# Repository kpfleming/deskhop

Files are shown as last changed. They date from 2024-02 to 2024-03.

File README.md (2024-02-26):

#  DeskHop - Fast Desktop Switching
## JLCPCB version (see below)

Did you ever notice how, in the crazy world of tech, there's always that one quirky little project trying to solve a problem so niche that its only competitors might be a left-handed screwdriver and a self-hiding alarm clock?

I use two different computers in my daily workflow and share a single keyboard/mouse pair between them. Trying several USB switching boxes found on Amazon made me realize they all suffer from similar issues - it takes a while to switch, the process is quite clumsy when trying to find the button and frankly, it just doesn't get any better with time. 

All I wanted was a way to use a keyboard shortcut to quickly switch outputs, paired with the ability to do the same by magically moving the mouse pointer between monitors. This project enables you to do both, even if your computers run different operating systems!



## Features

- Completely **free and open source**
- No noticeable delay when switching
- Simply drag the mouse pointer between computers
- No software installed
- Affordable and obtainable components (<15€)
- 3D printable snap-fit case
- Full Galvanic isolation between your outputs
- Works with Linux, macOS and Windows

------

## How it works

The device acts as an intermediary between your keyboard/mouse and the computer, establishing and maintaining connections with both computers at once. Then it chooses where to forward your mouse and keystrokes to, depending on your selection. Keyboard follows the mouse and vice versa, so just dragging the mouse to the other desktop will switch both.

## Mouse 

To get the mouse cursor to magically jump across, the mouse hid report descriptor was changed to use absolute coordinates and then the mouse reports (that still come in relative movements) accumulate internally, keeping the accurate tally on the position. 

When you try to leave the monitor area in the direction of the other monitor, it keeps the Y coordinate and swaps the maximum X for a minimum X, then flips the outputs. This ensures that the cursor seamlessly appears at the same height on the other monitor, enhancing the perception of a smooth transition.



 <p align="center"> Dragging the mouse from Mac to Linux automatically switches outputs. 
 </p>

-----
 
The actual switch happens at the very moment when one arrow stops moving and the other one starts.

## Keyboard

Acting as a USB Host and querying your keyboard periodically, it looks for a preconfigured hotkey in the hid report (usually Caps Lock for me). When found, it will forward all subsequent characters to the other output.

To have a visual indication which output you are using at any given moment, you can repurpose keyboard LEDs and have them provide the necessary feedback. 

It also remembers the LED state for each computer, so you can pick up exactly how you left it. 



## How to build

```
PICO_BOARD=pico PICO_SDK_PATH=/your/sdk/path cmake -S . -B build
cmake --build build
```

## Using pre-built images

Alternatively, you can use the [pre-built images](binaries/). Take the Pico board that goes to slot A on the PCB and hold the on-board button while connecting the cable.

It should appear as a USB drive on your system. Copy the corresponding board_A.uf2 file there and repeat the same with B.

## Upgrading firmware

Option 1 - Open the case, hold the button while connecting each Pico and copy the right uf2 to it.

Option 2 - Switch a board to BOOTSEL mode by using a special key combination (listed below). 

This will make the corresponding Pico board enter the bootloader upgrade mode and act as USB flash drive. Now you can drag-and-drop the .uf2 file to it (you might need to plug in your mouse directly).

## Misc features

### Mouse slowdown

Ever tried to move that YT video slider to a specific position but your mouse moves too jumpy and suddenly you are moving your hand super-carefully like you're 5 and playing "Operation" all over again?

**Press right CTRL + right ALT** to toggle a slow-mouse mode. The mouse pointer will slow down considerably, enabling you to get the finer precision work done and still have your mouse moving normally by quickly pressing the same keys again.

### Switch Lock

If you want to lock yourself to one screen, use ```RIGHT CTRL + L```.
This will make sure you won't accidentally leave your current screen. To turn off, press the same key combo again.

### Screensaver

Supposedly built in to prevent computer from entering standby, but truth be told - it is just fun to watch. Off by default, will make your mouse pointer bounce around the screen like a Pong ball. When enabled, it activates after a period of inactivity defined in user config header and automatically switches off as soon as you send any output towards that screen. 



## Hardware

[The circuit](schematics/DeskHop.pdf) is based on two Raspberry Pi Pico boards, chosen because they are cheap (4.10 € / pc), can be hand soldered and most suppliers have them in stock.

The Picos are connected using UART and separated by an Analog Devices ADuM1201 dual-channel digital isolator (~3€). 

While they normally don't have support for dual USB, thanks to an [amazing project](https://github.com/sekigon-gonnoc/Pico-PIO-USB) where USB is implemented using the programmable IO wizardry found in RP2040, there is support for it to act both as an USB host and device.  

## PCB

To keep things as simple as possible for DIY builds, the traces were kept on one side and the number of parts kept to a theoretical minimum.



USB D+/D- differential lines should be identical in length, but they are slightly asymmetrical on purpose to counter the length difference on the corresponding GPIO traces PICO PCB itself, so the overall lengths should match.

Zd (differential impedance) is aimed as 90 ohm (managed to get ~107, close enough :)).

The thickness is designed to be 1.6 mm for snap-fit to work as expected.

Planned changes:
- Add 15 ohm resistors for D+ / D- lines
- Add decoupling capacitance near VBUS line on USB-A connector (~100 uF)
- Add an ESD protection device near the USB connector
- Add indications on the silkscreen for pin1 on the ADuM1201
- Add indications on the silkscreen for which Raspberry Pi Pico pins need to be soldered

... done, waiting on PCBs to re-test and verify everything. Stay tuned for an updated version!

## Case

Since I'm not very good with 3d, the case is [simple and basic](case/) but does the job. It should be easy to print, uses ~33g of filament and takes a couple of hours.

Horizontal PCB movements are countered by pegs sliding through holes and vertical movements by snap-fit lugs on the side - no screws required.

Micro USB connectors on both boards are offset from the side of the case, so slightly larger holes should allow for cables to reach in. 

The lid is of a snap-fit design, with a screwdriver slot for opening. The markings on top are recessed and can be finished with e.g. crayons to give better contrast (or simply left as-is).



## Bill of materials

Note that this fork of the project has been converted to use parts
from [LCSC](https://www.lcsc.com/), specifically parts that are kept
in stock at JLCPCB. This reduces costs and shortens assembly times,
but is only useful if you plan on ordering fully-assembled boards from
JLCPCB.

Prices quoted below are from a qty 10 unit order on 2024-02-26.

| Component | Qty | LCSC SKU | Unit Price / $ | Price / $|
|---|-----|---|---|---|
| Raspberry Pi Pico  | 2 | C7203002 | 5.93 | 11.85 |
| ISO7721DRRZ | 1 | C366164  | 0.56 |  0.56 |
| Cap 1206 SMD 100nF | 2 | C2858367 | 0.013 |  0.03 |
| USB-A PCB conn. | 2 | C42411 | 0.049 |  0.10 |
| Headers 2.54 1x03  | 2 | C2915006 | 0.176 |  0.35 |
| | | | | |
| | | | Total | 12.89 |

Additional steps:

 - making the PCB ([Gerber provided](pcb/), choose 1.6 mm thickness)
 - 3d printing the case ([stl files provided](case/), ~33g filament)

## Assembly guide

If you have some experience with electronics, you don't need this. However, some of you might not, and in that case this video might help guide you through the process. Please note, after soldering you should clean the flux from the PCB to prevent corrosion. 

The standard process to do that is using isopropyl alcohol and an old toothbrush. But guess what? I'm not putting my old toothbrush online, so you'll just have to improvise that part :)

PCB Assembly Guide (https://www.youtube.com/watch?v=LxI9NYi_oOU)

## Usage guide

### Keyboard shortcuts

_Firmware upgrade_
- ```Right Shift + F12 + Left Shift + A``` - put board A in FW upgrade mode
- ```Right Shift + F12 + Left Shift + B``` - put board B in FW upgrade mode

_Usage_
- ```Right CTRL + Right ALT``` - Toggle slower mouse mode
- ```Right CTRL + L``` - Lock/Unlock mouse desktop switching
- ```Caps Lock``` - Switch between outputs

_Config_
- ```Right Shift + F12 + D``` - remove flash config
- ```Right Shift + F12 + Y``` - save screen switch offset
- ```Right Shift + F12 + S``` - turn on/off screensaver option

### Switch cursor height calibration

This step is not required, but it can be handy if your screens are not perfectly aligned or differ in size. The objective is to have the mouse pointer come out at exactly the same height.



Just park your mouse on the LARGER screen at the height of the smaller/lower screen (illustrated) and press ```Right Shift + F12 + Y```. Your LED (and caps lock) should flash in confirmation.

Repeat for the bottom border (if it's above the larger screen's border). This will get saved to flash and it should keep this calibration value from now on.

### Other configuration

Mouse speed can now be configured per output screen and per axis. If you have multiple displays under Linux, your X speed is probably too fast, so you need to configure it in user_config.h and rebuild. In the future, this will be configurable without having to do that.

### Functional verification

When you connect a new USB peripheral, the board will flash the led twice, and instruct the other board to do the same. This way you can test if USB and outgoing communication works for each board.

Do this test by first plugging the keyboard on one side and then on the other. If everything is OK, leds will flash quickly back and forth in both cases.

## Security and Safety

Some features are missing on purpose, despite the fact it would make the device easier to use or simpler to configure. Here is a quick breakdown of these decisions:

- There is no copy-paste or *any* information sharing between systems. This prevents information leakage.
- No webhid device management or any inbound connectivity from the output computers, with the only exception of standard keyboard LED on/off messages, hard limited to 1 byte of data.
- No FW upgrade triggering from the outputs. Only explicit and deliberate user action through a special keyboard shortcut may do that.
- No plugged-in keyboard/mouse custom endpoints are exposed or information forwarded towards these devices. Their potential vulnerabilities are effectively firewalled from the computer.
- No input history is allowed to be retained.
- Outputs are physically separated and galvanically isolated with a minimal isolation voltage of 2kV.
- All packets exchanged between devices are of fixed length, no code is transferred and no raw config exchange of any kind can take place.
- There is no bluetooth or wifi, networking, Internet access, usb drives etc.
- No connected computer is considered trusted under any circumstances.
- Entirety of the code is open source, without any binary blobs and thoroughly commented to explain its purpose. I encourage you to never trust anyone and always make sure you know what you are running by doing a manual audit.

This still doesn't guarantee anything, but I believe it makes a reasonable set of ground rules to keep you safe and protected.

## FAQ

1. I just have two Picos, can I do without a PCB and isolator?

*Sure. Having an isolator is recommended but it should work without it.*

2. What happens if I have two different resolutions on my monitors?

*The mouse movement is done in abstract coordinate space and your computer figures out how that corresponds with the physical screen, so it should just work.*

3. Where can I buy it?

*I'm not selling anything, this is just a personal, non-commercial hobby project.*

*[update] There is a manufacturing/assembly company in China that might offer PCBs in qty of 1, assembled boards and boards + case, so stay tuned.*

*I **don't want to take any commission** on this - the only goal is to provide an alternative for people who don't feel confident enough to assemble the boards themselves.*

4. When the active screen is changed via the mouse, does the keyboard follow (and vice versa)?

*Yes, the idea was to make it behave like it was one single computer.*

5. Will this work with keyboard/mouse combo dongles, like the Logitech Unifying receiver?

*Not tested yet, but the latest version might actually work (please provide feedback).*

6. Will this work with wireless mice and keyboards that have separate wireless receivers (one for the mouse, another for the keyboard)?

*It should work - tried an Anker wireless mouse with a separate receiver and that worked just fine.*

7. I have issues with build or compilation

*Check out the [Troubleshooting Wiki](https://github.com/hrvach/deskhop/wiki/Troubleshooting) that might have some answers.*

## Software Alternatives

There are several software alternatives you can use if that works in your particular situation.

1. [Barrier](https://github.com/debauchee/barrier) - Free, Open Source
2. [Input Leap](https://github.com/input-leap/input-leap) - Free, Open Source
3. [Synergy](https://symless.com/synergy) - Commercial
4. [Mouse Without Borders](https://www.microsoft.com/en-us/garage/wall-of-fame/mouse-without-borders/) - Free, Windows only
5. [Universal Control](https://support.apple.com/en-my/HT212757) - Free, Apple thing

## Shortcomings

- Windows 10 broke HID absolute coordinates behavior in KB5003637, so you can't use more than 1 screen on Windows (mouse will stay on the main screen).
- Code needs cleanup, some refactoring etc.
- Occasional bugs and weird behavior.
- Not tested with a wide variety of devices, I don't know how it will work with your hardware. There is a reasonable chance things might not work out-of-the-box. 
- Advanced keyboards (with knobs, extra buttons or sliders) will probably face issues where this additional hardware doesn't work.
- Super-modern mice with 300 buttons might see some buttons not work as expected.
- NOTE: Both computers need to be connected and provide power to the USB for this to work (as each board gets powered by the computer it plugs into). Many desktops and laptops will provide power even when shut down nowadays. If you need to run with one board fully disconnected, you should be able to use a USB hub to plug both keyboard and mouse to a single port.

## Progress

So, what's the deal with all the enthusiasm? I can't believe it - please allow me to thank you all! I've never expected this kind of interest in a simple personal project, so the initial features are pretty basic (just like my cooking skills) and mostly cover my own usecase. Stay tuned for firmware updates that should bring wider device compatibility, more features and less bugs. As this is a hobby project, I appreciate your understanding for being time-constrained and promise to do the best I can.

Planned features:
- ~~Proper TinyUSB host integration~~ (done)
- ~~HID report protocol parsing, not just boot protocol~~ (mostly done)
- ~~Support for unified dongle receivers~~
- ~~Support for USB hubs and single-sided operation~~
- Configurable screens (partially)
- ~~Permament configuration stored in flash~~
- Better support for keyboards with knobs and mice with mickeys
- Unified firmware for both Picos
- ... and more!

Working on a *lite* version which provides basic functionality with just a single Pico W board, lowering the cost even further and enabling you to try it out even with no added hardware or PCB.

Mouse polling should now work at 1000 Hz (the dips in the graph is my arm hurting from all the movement :-)):

Mouse polling rate

## Disclaimer

I kindly request that anyone attempting to build this project understands and acknowledges that I am not liable for any injuries, damages, or other consequences. Your safety is important, and I encourage you to approach this project carefully, taking necessary precautions and assuming personal responsibility for your well-being throughout the process. Please don't get electrocuted, burned, stressed or angry. Have fun and enjoy! 

Happy switchin'!

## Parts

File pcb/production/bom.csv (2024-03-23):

Designator | Footprint | Quantity | Value | LCSC Part #
C101, C102, C202, C205, C206, C207, C208, C209, C210, C211, C212, C302, C305, C306, C307, C308, C309, C310, C311, C312 | 0402 | 20 | 100n | C541405
C201, C203, C204, C301, C303, C304 | 0402 | 6 | 2u2 | C541409
C214, C215, C314, C315 | 0402 | 4 | 1u | C106253
D201, D301 | 0603 | 2 | Active | C5875737
D202, D302 | SOD-323_L1.7-W1.3-LS2.6-RD-1 | 2 | 1N5817WS SJ | C2828424
J202, J302 | USB-C-SMD_G-SWITCH_GT-USB-7010ASV | 2 | Computer | C2988369
J203, J303 | USB-C-SMD_G-SWITCH_GT-USB-7010ASV | 2 | Power | C2988369
J204, J304 | USB-C-SMD_G-SWITCH_GT-USB-7010ASV | 2 | Device | C2988369
KEY201, KEY301 | KEY-SMD_4P-L4.2-W3.2-P2.20-LS4.6 | 2 | BOOTSEL | C470427
Q201, Q301 | SOT-23-3_L2.9-W1.3-P0.95-LS2.4-BR-1 | 2 | USB Power Switch | C2940629
R201, R301 | 0402 | 2 | 1K | C144789
R202, R302 | 0402 | 2 | 470R | C227095
R203, R204, R205, R206, R303, R304, R305, R306 | 0402 | 8 | 27R | C138021
R207, R208, R210, R211, R307, R308, R310, R311 | 0402 | 8 | 5K1 | C144745
R209, R212, R213, R309, R312, R313 | 0402 | 6 | 22K | C144778
U101 | SOIC-8_3.9x4.9mm_P1.27mm | 1 | Digital Isolator | C366164
U201, U301 | SOIC-8_L5.3-W5.3-P1.27-LS8.0-BL | 2 | 16Mb NOR Flash | C82317
U202, U302 | SOT-23-3_L3.0-W1.7-P0.95-LS2.9-BR | 2 | 3V3 250ma LDO Regulator | C347376
U203, U303 | RP2040-QFN-56 | 2 | Microcontroller | C2040
X201, X301 | OSC-SMD_4P-L3.2-W2.5-BL-1 | 2 | 12MHz CMOS Oscillator | C387348

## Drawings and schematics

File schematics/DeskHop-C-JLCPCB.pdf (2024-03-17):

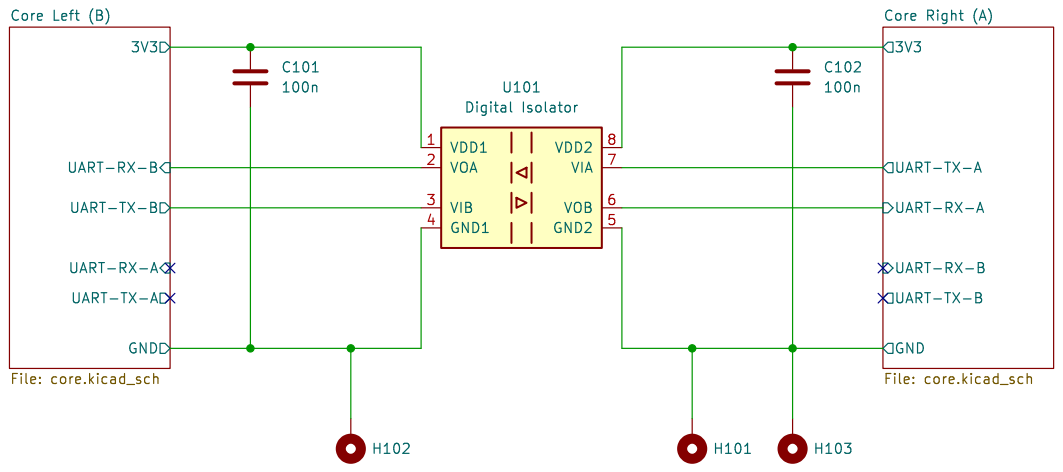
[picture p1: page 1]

UART-TX-B UART-RX-B UART-TX-A UART-RX-A Core Right (A) File: core.kicad_sch
3V3 GND

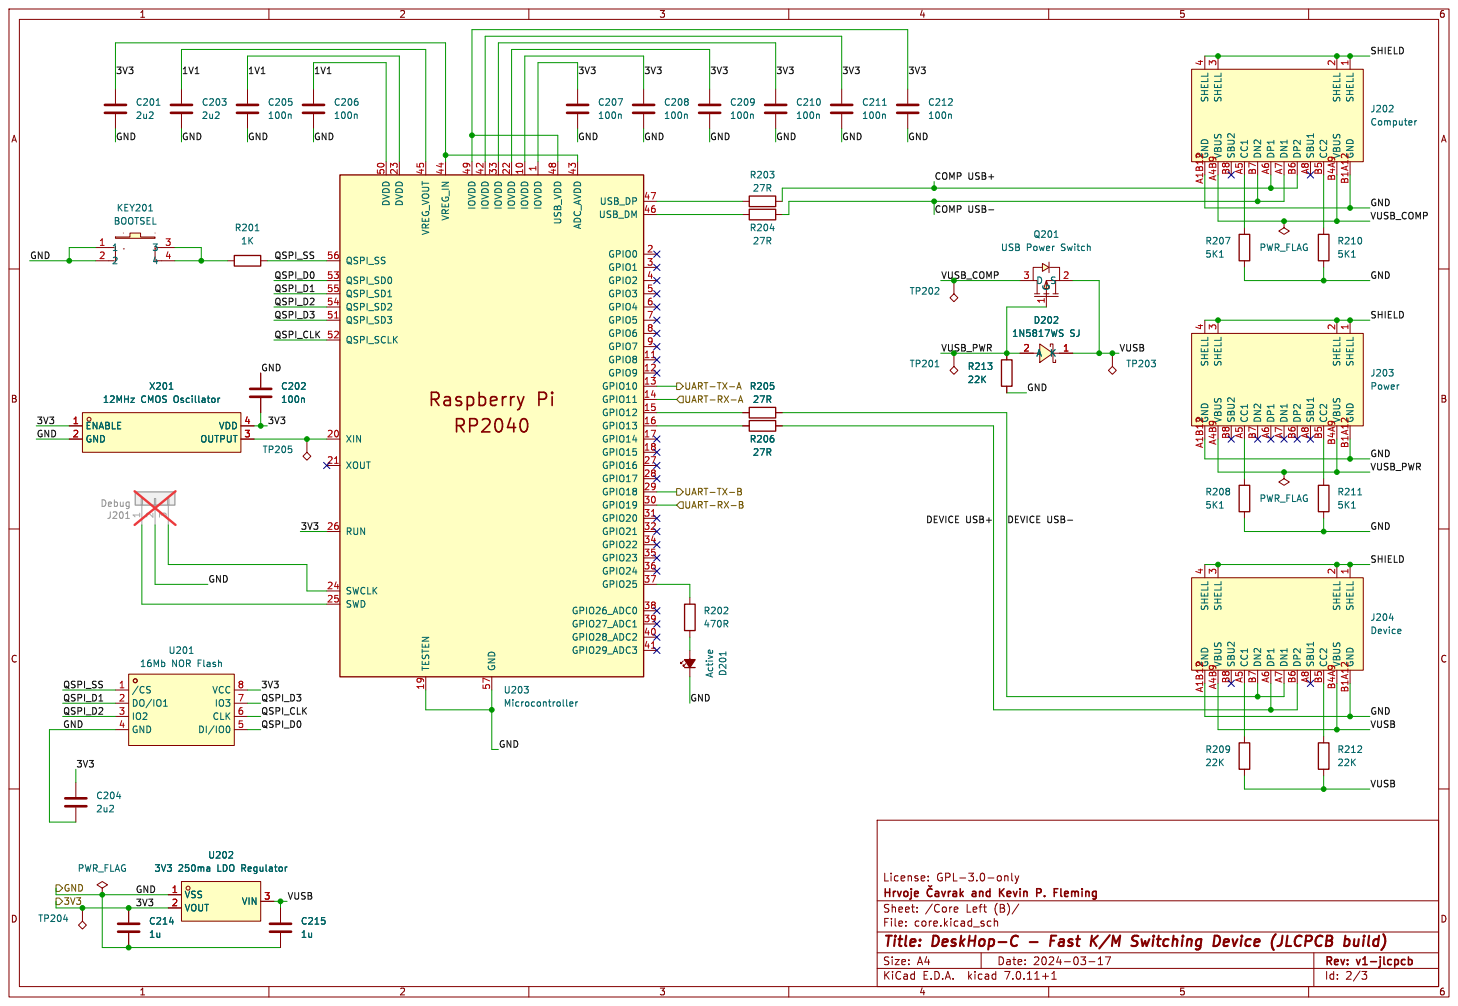
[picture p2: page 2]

COMP USB+ COMP USB- 3V3 GND

1 IOVDD 10 GPIO8 11 GPIO9 12 GPIO10 13 GPIO11 14 GPIO12 15 GPIO13 16 GPIO14 17 GPIO15 18 TESTEN 19 GPIO0 2 XIN 20 XOUT 21 IOVDD 22 DVDD 23 SWCLK 24 SWD 25 RUN 26 GPIO16 27 GPIO17 28 GPIO18 29 GPIO1 3 GPIO19 30 GPIO20 31 GPIO21 32 IOVDD 33 GPIO22 34 GPIO23 35 GPIO24 36 GPIO25 37 GPIO26_ADC0 38 GPIO27_ADC1 39 GPIO2 4 GPIO28_ADC2 40 GPIO29_ADC3 41 IOVDD 42 ADC_AVDD 43 VREG_IN 44 VREG_VOUT 45 USB_DM 46 USB_DP 47 USB_VDD 48 IOVDD 49 GPIO3 5 DVDD 50 QSPI_SD3 51 QSPI_SCLK 52 QSPI_SD0 53 QSPI_SD2 54 QSPI_SD1 55 QSPI_SS 56 GND 57 GPIO4 6 GPIO5 7 GPIO6 8 GPIO7 9 U203 Microcontroller SHELL

3 Debug ENABLE 1 GND 2 OUTPUT 3 VDD 4 X201

UART-RX-A UART-TX-A

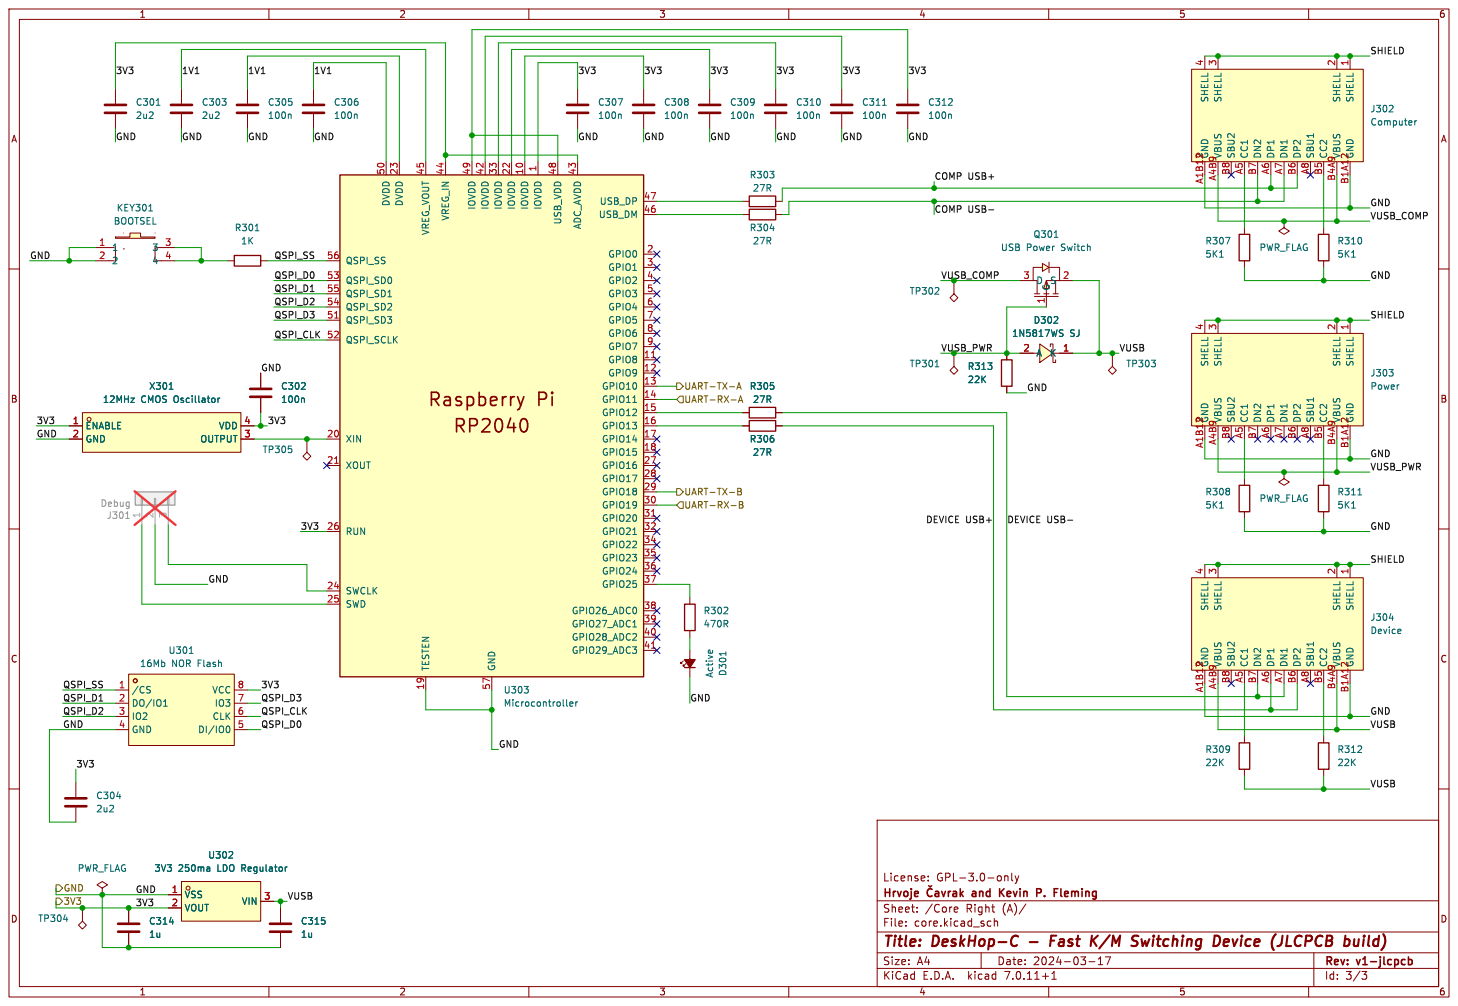
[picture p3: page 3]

COMP USB+ COMP USB- 3V3 GND

1 IOVDD 10 GPIO8 11 GPIO9 12 GPIO10 13 GPIO11 14 GPIO12 15 GPIO13 16 GPIO14 17 GPIO15 18 TESTEN 19 GPIO0 2 XIN 20 XOUT 21 IOVDD 22 DVDD 23 SWCLK 24 SWD 25 RUN 26 GPIO16 27 GPIO17 28 GPIO18 29 GPIO1 3 GPIO19 30 GPIO20 31 GPIO21 32 IOVDD 33 GPIO22 34 GPIO23 35 GPIO24 36 GPIO25 37 GPIO26_ADC0 38 GPIO27_ADC1 39 GPIO2 4 GPIO28_ADC2 40 GPIO29_ADC3 41 IOVDD 42 ADC_AVDD 43 VREG_IN 44 VREG_VOUT 45 USB_DM 46 USB_DP 47 USB_VDD 48 IOVDD 49 GPIO3 5 DVDD 50 QSPI_SD3 51 QSPI_SCLK 52 QSPI_SD0 53 QSPI_SD2 54 QSPI_SD1 55 QSPI_SS 56 GND 57 GPIO4 6 GPIO5 7 GPIO6 8 GPIO7 9 U303 Microcontroller SHELL

3 Debug ENABLE 1 GND 2 OUTPUT 3 VDD 4 X301

UART-RX-A UART-TX-A

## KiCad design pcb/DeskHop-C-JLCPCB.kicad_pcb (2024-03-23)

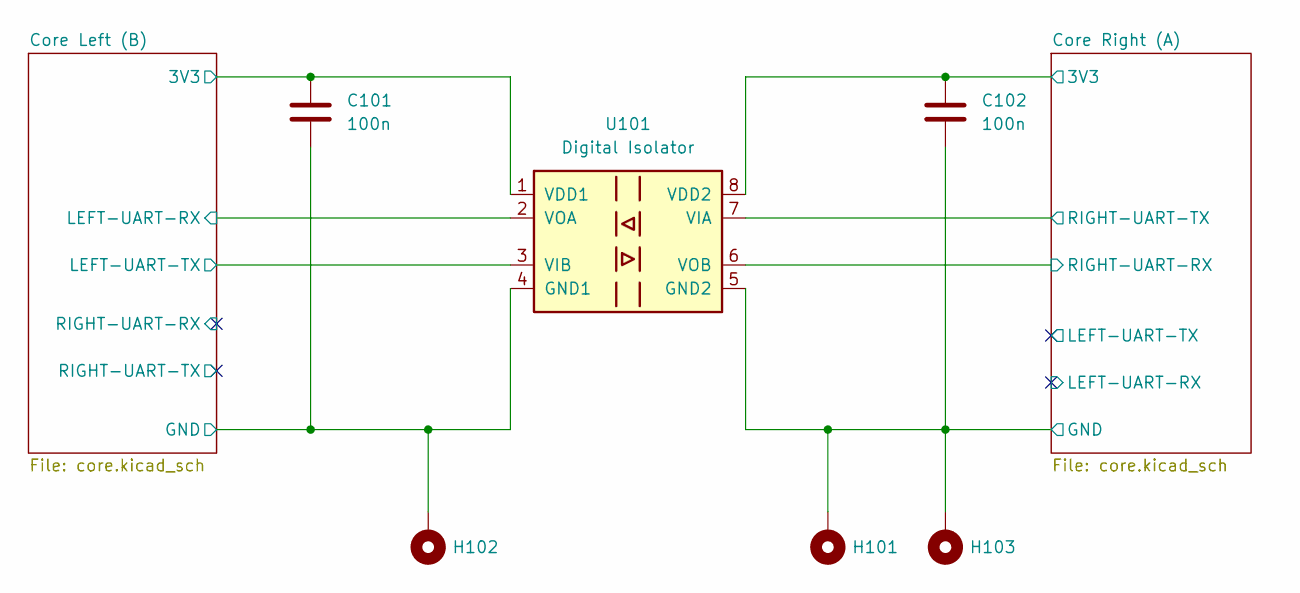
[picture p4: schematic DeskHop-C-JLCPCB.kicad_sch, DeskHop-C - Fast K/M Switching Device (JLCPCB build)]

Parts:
C101, C102: 100n; C_0402_1005Metric; MPN CC0402KRX5R5BB104; LCSC C541405
H101, H102, H103: MountingHole_Pad; MountingHole_2.7mm_M2.5_Pad_Via
U101: Digital Isolator; SOIC-8_3.9x4.9mm_P1.27mm; MPN ISO7721DR; LCSC C366164

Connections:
/Core Left (B)/3V3: C101.1, U101.1 (VDD1); also elsewhere on the board
/Core Left (B)/GND: C101.2, H102.1, U101.4 (GND1); also elsewhere on the board
/Core Left (B)/LEFT-UART-RX: U101.2 (VOA); also elsewhere on the board
/Core Left (B)/LEFT-UART-TX: U101.3 (VIB); also elsewhere on the board
/Core Right (A)/3V3: C102.1, U101.8 (VDD2); also elsewhere on the board
/Core Right (A)/GND: C102.2, H101.1, H103.1, U101.5 (GND2); also elsewhere on the board
/Core Right (A)/RIGHT-UART-RX: U101.6 (VOB); also elsewhere on the board
/Core Right (A)/RIGHT-UART-TX: U101.7 (VIA); also elsewhere on the board

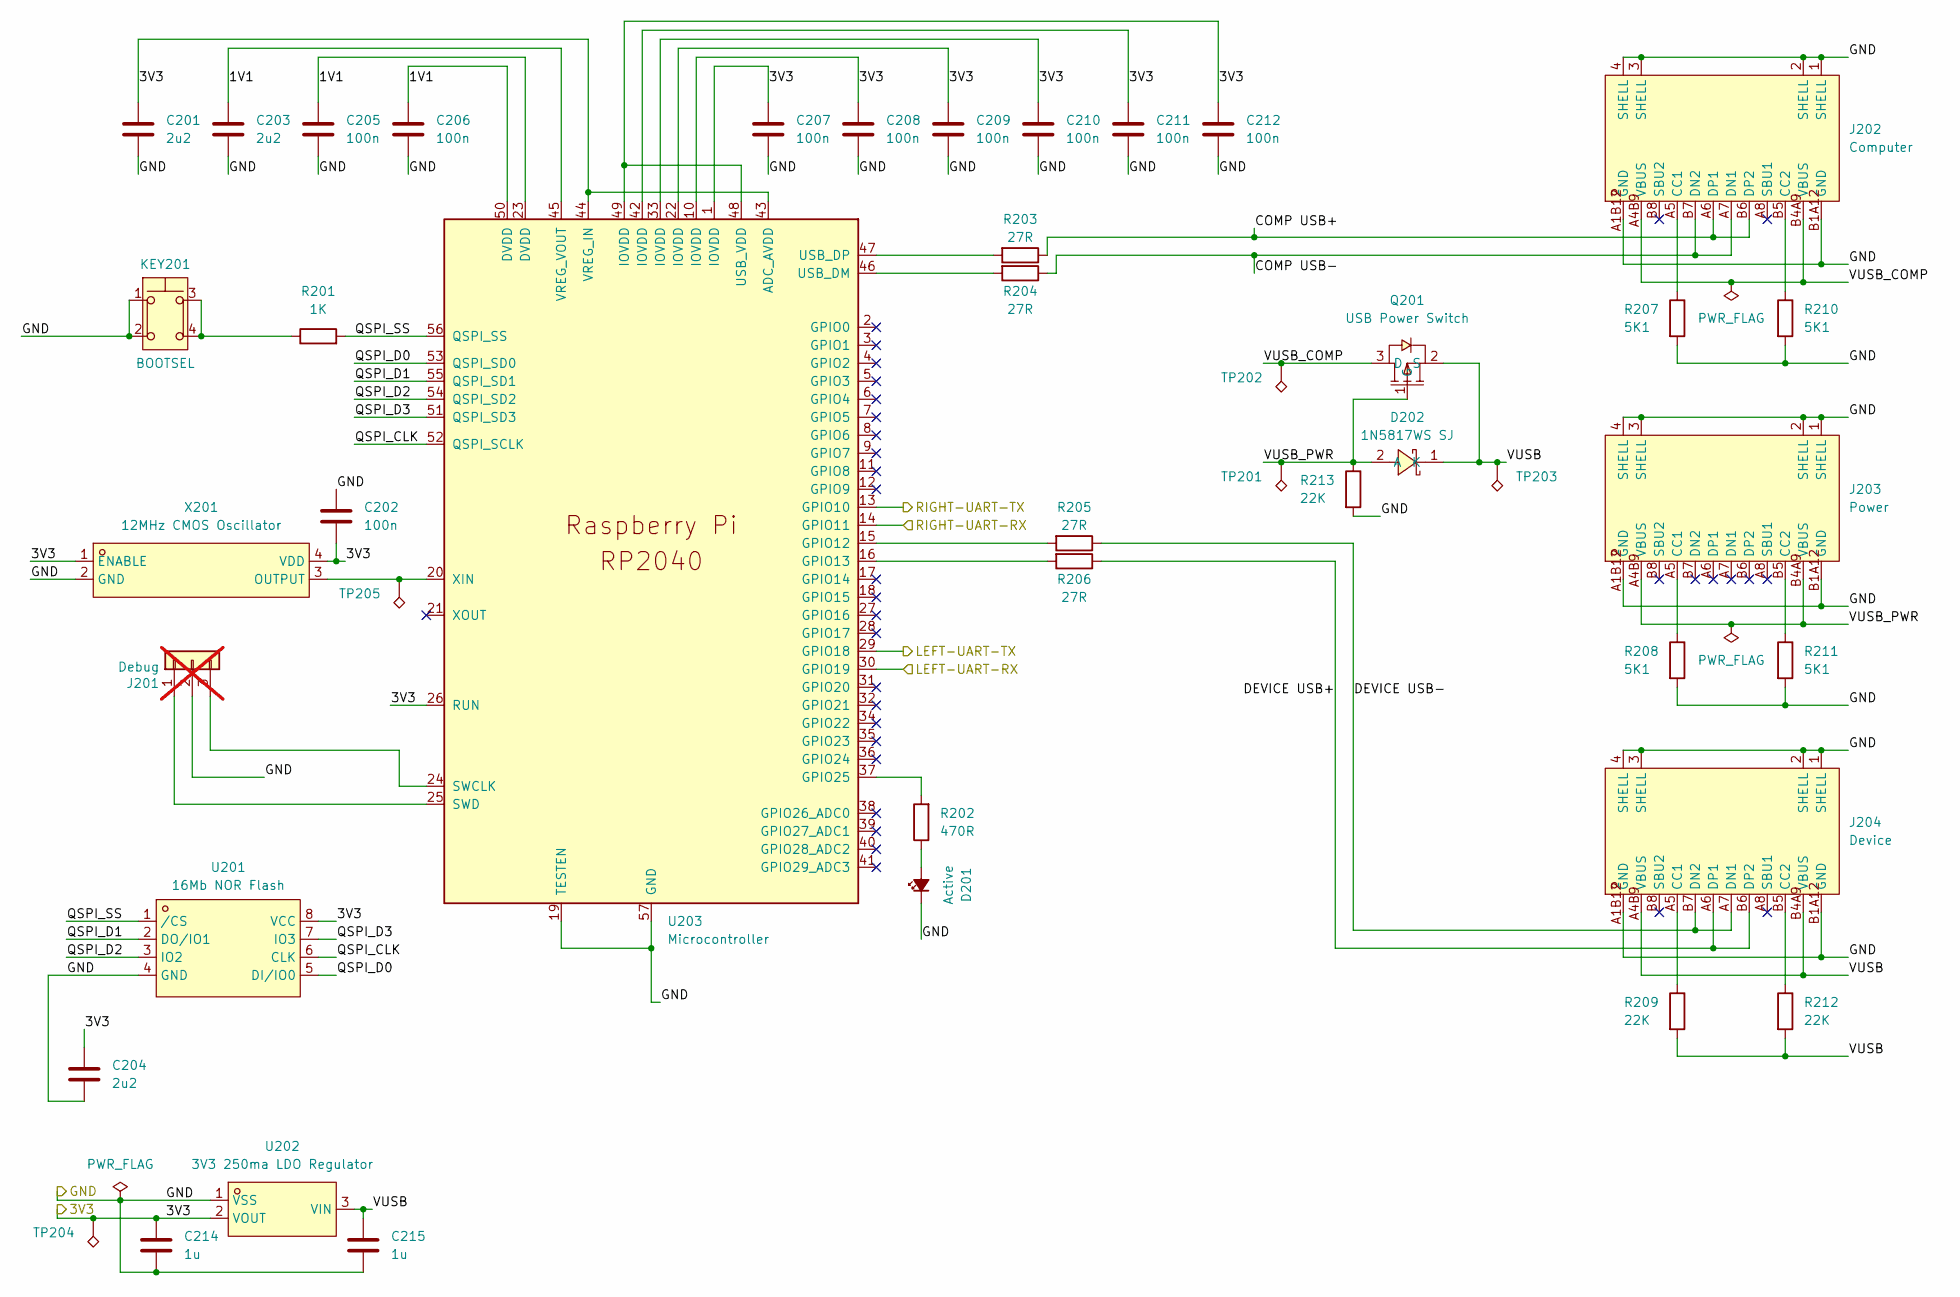
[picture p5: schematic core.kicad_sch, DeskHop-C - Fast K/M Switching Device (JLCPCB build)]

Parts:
C201, C203, C204: 2u2; C_0402_1005Metric; MPN CC0402KRX5R5BB225; LCSC C541409
C202, C205, C206, C207, C208, C209, C210, C211, C212: 100n; C_0402_1005Metric; MPN CC0402KRX5R5BB104; LCSC C541405
C214, C215: 1u; C_0402_1005Metric; MPN CC0402KRX5R5BB105; LCSC C106253
D201: Active; LED_0603_1608Metric; MPN NCD0805B2APG1608CGKC/T; LCSC C5875737
D202: 1N5817WS SJ; SOD-323_L1.7-W1.3-LS2.6-RD-1; MPN 1N5817WS; LCSC C2828424
J201: Debug; PinHeader_1x03_P2.54mm_Vertical; not fitted
J202: Computer; USB-C-SMD_G-SWITCH_GT-USB-7010ASV; MPN GT-USB-7010ASV; LCSC C2988369
J203: Power; USB-C-SMD_G-SWITCH_GT-USB-7010ASV; MPN GT-USB-7010ASV; LCSC C2988369
J204: Device; USB-C-SMD_G-SWITCH_GT-USB-7010ASV; MPN GT-USB-7010ASV; LCSC C2988369
KEY201: BOOTSEL; KEY-SMD_4P-L4.2-W3.2-P2.20-LS4.6; MPN SKRPASE010; LCSC C470427
Q201: USB Power Switch; SOT-23-3_L2.9-W1.3-P0.95-LS2.4-BR-1; MPN DMG2305UX; LCSC C2940629
R201: 1K; R_0402_1005Metric; MPN AC0402FR-071KL; LCSC C144789
R202: 470R; R_0402_1005Metric; MPN AC0402FR-07470RL; LCSC C227095
R203, R204, R205, R206: 27R; R_0402_1005Metric; MPN RC0402FR-0727RL; LCSC C138021
R207, R208, R210, R211: 5K1; R_0402_1005Metric; MPN AC0402FR-075K1L; LCSC C144745
R209, R212, R213: 22K; R_0402_1005Metric; MPN AC0402FR-0722KL; LCSC C144778
TP201, TP202, TP203, TP204, TP205: TestPoint_Alt; TestPoint_Pad_1.0x1.0mm
U201: 16Mb NOR Flash; SOIC-8_L5.3-W5.3-P1.27-LS8.0-BL; MPN W25Q16JVSSIQ; LCSC C82317
U202: 3V3 250ma LDO Regulator; SOT-23-3_L3.0-W1.7-P0.95-LS2.9-BR; MPN XC6206P332MR; LCSC C347376
U203: Microcontroller; RP2040-QFN-56; MPN RP2040; LCSC C2040
X201: 12MHz CMOS Oscillator; OSC-SMD_4P-L3.2-W2.5-BL-1; MPN S3D12.000000B20F30T; LCSC C387348

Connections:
/Core Left (B)/1V1: C203.2, C205.2, C206.2, U203.23 (DVDD), U203.45 (VREG_VOUT), U203.50 (DVDD)
/Core Left (B)/3V3: C201.2, C202.1, C204.1, C207.2, C208.2, C209.2, C210.2, C211.2, C212.2, C214.1, TP204.1, U201.8 (VCC), U202.2 (VOUT), U203.1 (IOVDD), U203.10 (IOVDD), U203.22 (IOVDD), U203.26 (RUN), U203.33 (IOVDD), U203.42 (IOVDD), U203.43 (ADC_AVDD), U203.44 (VREG_IN), U203.48 (USB_VDD), U203.49 (IOVDD), X201.1 (ENABLE), X201.4 (VDD); also elsewhere on the board
/Core Left (B)/COMP USB+: J202.A6 (DP1), J202.B6 (DP2), R203.1
/Core Left (B)/COMP USB-: J202.A7 (DN1), J202.B7 (DN2), R204.1
/Core Left (B)/DEVICE USB+: J204.A6 (DP1), J204.B6 (DP2), R205.1
/Core Left (B)/DEVICE USB-: J204.A7 (DN1), J204.B7 (DN2), R206.1
/Core Left (B)/GND: C201.1, C202.2, C203.1, C204.2, C205.1, C206.1, C207.1, C208.1, C209.1, C210.1, C211.1, C212.1, C214.2, C215.2, D201.1 (K), J201.2, J202.1 (SHELL), J202.2 (SHELL), J202.3 (SHELL), J202.4 (SHELL), J202.A1B12 (GND), J202.B1A12 (GND), J203.1 (SHELL), J203.2 (SHELL), J203.3 (SHELL), J203.4 (SHELL), J203.A1B12 (GND), J203.B1A12 (GND), J204.1 (SHELL), J204.2 (SHELL), J204.3 (SHELL), J204.4 (SHELL), J204.A1B12 (GND), J204.B1A12 (GND), KEY201.1, KEY201.2, R207.2, R208.2, R210.2, R211.2, R213.2, U201.4 (GND), U202.1 (VSS), U203.19 (TESTEN), U203.57 (GND), X201.2 (GND); also elsewhere on the board
/Core Left (B)/LEFT-UART-RX: U203.30 (GPIO19); also elsewhere on the board
/Core Left (B)/LEFT-UART-TX: U203.29 (GPIO18); also elsewhere on the board
/Core Left (B)/QSPI_CLK: U201.6 (CLK), U203.52 (QSPI_SCLK)
/Core Left (B)/QSPI_D0: U201.5 (DI/IO0), U203.53 (QSPI_SD0)
/Core Left (B)/QSPI_D1: U201.2 (DO/IO1), U203.55 (QSPI_SD1)
/Core Left (B)/QSPI_D2: U201.3 (IO2), U203.54 (QSPI_SD2)
/Core Left (B)/QSPI_D3: U201.7 (IO3), U203.51 (QSPI_SD3)
/Core Left (B)/QSPI_SS: R201.2, U201.1 (/CS), U203.56 (QSPI_SS)
/Core Left (B)/RIGHT-UART-RX: U203.14 (GPIO11)
/Core Left (B)/RIGHT-UART-TX: U203.13 (GPIO10)
/Core Left (B)/VUSB: C215.1, D202.1 (K), J204.A4B9 (VBUS), J204.B4A9 (VBUS), Q201.2 (S), R209.2, R212.2, TP203.1, U202.3 (VIN)
/Core Left (B)/VUSB_COMP: J202.A4B9 (VBUS), J202.B4A9 (VBUS), Q201.3 (D), TP202.1
/Core Left (B)/VUSB_PWR: D202.2 (A), J203.A4B9 (VBUS), J203.B4A9 (VBUS), Q201.1 (G), R213.1, TP201.1
unnamed: D201.2 (A), R202.1
unnamed: J201.1, U203.25 (SWD)
unnamed: J201.3, U203.24 (SWCLK)
unnamed: J202.A5 (CC1), R207.1
unnamed: J202.B5 (CC2), R210.1
unnamed: J203.A5 (CC1), R208.1
unnamed: J203.B5 (CC2), R211.1
unnamed: J204.A5 (CC1), R209.1
unnamed: J204.B5 (CC2), R212.1
unnamed: KEY201.3, KEY201.4, R201.1
unnamed: R206.2, U203.15 (GPIO12)
unnamed: R205.2, U203.16 (GPIO13)
unnamed: R202.2, U203.37 (GPIO25)
unnamed: R204.2, U203.46 (USB_DM)
unnamed: R203.2, U203.47 (USB_DP)
unnamed: TP205.1, U203.20 (XIN), X201.3 (OUTPUT)

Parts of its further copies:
C301, C303, C304: 2u2; C_0402_1005Metric; MPN CC0402KRX5R5BB225; LCSC C541409
C302, C305, C306, C307, C308, C309, C310, C311, C312: 100n; C_0402_1005Metric; MPN CC0402KRX5R5BB104; LCSC C541405
C314, C315: 1u; C_0402_1005Metric; MPN CC0402KRX5R5BB105; LCSC C106253
D301: Active; LED_0603_1608Metric; MPN NCD0805B2APG1608CGKC/T; LCSC C5875737
D302: 1N5817WS SJ; SOD-323_L1.7-W1.3-LS2.6-RD-1; MPN 1N5817WS; LCSC C2828424
J301: Debug; PinHeader_1x03_P2.54mm_Vertical; not fitted
J302: Computer; USB-C-SMD_G-SWITCH_GT-USB-7010ASV; MPN GT-USB-7010ASV; LCSC C2988369
J303: Power; USB-C-SMD_G-SWITCH_GT-USB-7010ASV; MPN GT-USB-7010ASV; LCSC C2988369
J304: Device; USB-C-SMD_G-SWITCH_GT-USB-7010ASV; MPN GT-USB-7010ASV; LCSC C2988369
KEY301: BOOTSEL; KEY-SMD_4P-L4.2-W3.2-P2.20-LS4.6; MPN SKRPASE010; LCSC C470427
Q301: USB Power Switch; SOT-23-3_L2.9-W1.3-P0.95-LS2.4-BR-1; MPN DMG2305UX; LCSC C2940629
R301: 1K; R_0402_1005Metric; MPN AC0402FR-071KL; LCSC C144789
R302: 470R; R_0402_1005Metric; MPN AC0402FR-07470RL; LCSC C227095
R303, R304, R305, R306: 27R; R_0402_1005Metric; MPN RC0402FR-0727RL; LCSC C138021
R307, R308, R310, R311: 5K1; R_0402_1005Metric; MPN AC0402FR-075K1L; LCSC C144745
R309, R312, R313: 22K; R_0402_1005Metric; MPN AC0402FR-0722KL; LCSC C144778
TP301, TP302, TP303, TP304, TP305: TestPoint_Alt; TestPoint_Pad_1.0x1.0mm
U301: 16Mb NOR Flash; SOIC-8_L5.3-W5.3-P1.27-LS8.0-BL; MPN W25Q16JVSSIQ; LCSC C82317
U302: 3V3 250ma LDO Regulator; SOT-23-3_L3.0-W1.7-P0.95-LS2.9-BR; MPN XC6206P332MR; LCSC C347376
U303: Microcontroller; RP2040-QFN-56; MPN RP2040; LCSC C2040
X301: 12MHz CMOS Oscillator; OSC-SMD_4P-L3.2-W2.5-BL-1; MPN S3D12.000000B20F30T; LCSC C387348

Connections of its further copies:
/Core Right (A)/1V1: C303.2, C305.2, C306.2, U303.23 (DVDD), U303.45 (VREG_VOUT), U303.50 (DVDD)
/Core Right (A)/3V3: C301.2, C302.1, C304.1, C307.2, C308.2, C309.2, C310.2, C311.2, C312.2, C314.1, TP304.1, U301.8 (VCC), U302.2 (VOUT), U303.1 (IOVDD), U303.10 (IOVDD), U303.22 (IOVDD), U303.26 (RUN), U303.33 (IOVDD), U303.42 (IOVDD), U303.43 (ADC_AVDD), U303.44 (VREG_IN), U303.48 (USB_VDD), U303.49 (IOVDD), X301.1 (ENABLE), X301.4 (VDD); also elsewhere on the board
/Core Right (A)/COMP USB+: J302.A6 (DP1), J302.B6 (DP2), R303.1
/Core Right (A)/COMP USB-: J302.A7 (DN1), J302.B7 (DN2), R304.1
/Core Right (A)/DEVICE USB+: J304.A6 (DP1), J304.B6 (DP2), R305.1
/Core Right (A)/DEVICE USB-: J304.A7 (DN1), J304.B7 (DN2), R306.1
/Core Right (A)/GND: C301.1, C302.2, C303.1, C304.2, C305.1, C306.1, C307.1, C308.1, C309.1, C310.1, C311.1, C312.1, C314.2, C315.2, D301.1 (K), J301.2, J302.1 (SHELL), J302.2 (SHELL), J302.3 (SHELL), J302.4 (SHELL), J302.A1B12 (GND), J302.B1A12 (GND), J303.1 (SHELL), J303.2 (SHELL), J303.3 (SHELL), J303.4 (SHELL), J303.A1B12 (GND), J303.B1A12 (GND), J304.1 (SHELL), J304.2 (SHELL), J304.3 (SHELL), J304.4 (SHELL), J304.A1B12 (GND), J304.B1A12 (GND), KEY301.1, KEY301.2, R307.2, R308.2, R310.2, R311.2, R313.2, U301.4 (GND), U302.1 (VSS), U303.19 (TESTEN), U303.57 (GND), X301.2 (GND); also elsewhere on the board
/Core Right (A)/LEFT-UART-RX: U303.30 (GPIO19)
/Core Right (A)/LEFT-UART-TX: U303.29 (GPIO18)
/Core Right (A)/QSPI_CLK: U301.6 (CLK), U303.52 (QSPI_SCLK)
/Core Right (A)/QSPI_D0: U301.5 (DI/IO0), U303.53 (QSPI_SD0)
/Core Right (A)/QSPI_D1: U301.2 (DO/IO1), U303.55 (QSPI_SD1)
/Core Right (A)/QSPI_D2: U301.3 (IO2), U303.54 (QSPI_SD2)
/Core Right (A)/QSPI_D3: U301.7 (IO3), U303.51 (QSPI_SD3)
/Core Right (A)/QSPI_SS: R301.2, U301.1 (/CS), U303.56 (QSPI_SS)
/Core Right (A)/RIGHT-UART-RX: U303.14 (GPIO11); also elsewhere on the board
/Core Right (A)/RIGHT-UART-TX: U303.13 (GPIO10); also elsewhere on the board
/Core Right (A)/VUSB: C315.1, D302.1 (K), J304.A4B9 (VBUS), J304.B4A9 (VBUS), Q301.2 (S), R309.2, R312.2, TP303.1, U302.3 (VIN)
/Core Right (A)/VUSB_COMP: J302.A4B9 (VBUS), J302.B4A9 (VBUS), Q301.3 (D), TP302.1
/Core Right (A)/VUSB_PWR: D302.2 (A), J303.A4B9 (VBUS), J303.B4A9 (VBUS), Q301.1 (G), R313.1, TP301.1
unnamed: D301.2 (A), R302.1
unnamed: J301.1, U303.25 (SWD)
unnamed: J301.3, U303.24 (SWCLK)
unnamed: J302.A5 (CC1), R307.1
unnamed: J302.B5 (CC2), R310.1
unnamed: J303.A5 (CC1), R308.1
unnamed: J303.B5 (CC2), R311.1
unnamed: J304.A5 (CC1), R309.1
unnamed: J304.B5 (CC2), R312.1
unnamed: KEY301.3, KEY301.4, R301.1
unnamed: R306.2, U303.15 (GPIO12)
unnamed: R305.2, U303.16 (GPIO13)
unnamed: R302.2, U303.37 (GPIO25)
unnamed: R304.2, U303.46 (USB_DM)
unnamed: R303.2, U303.47 (USB_DP)
unnamed: TP305.1, U303.20 (XIN), X301.3 (OUTPUT)

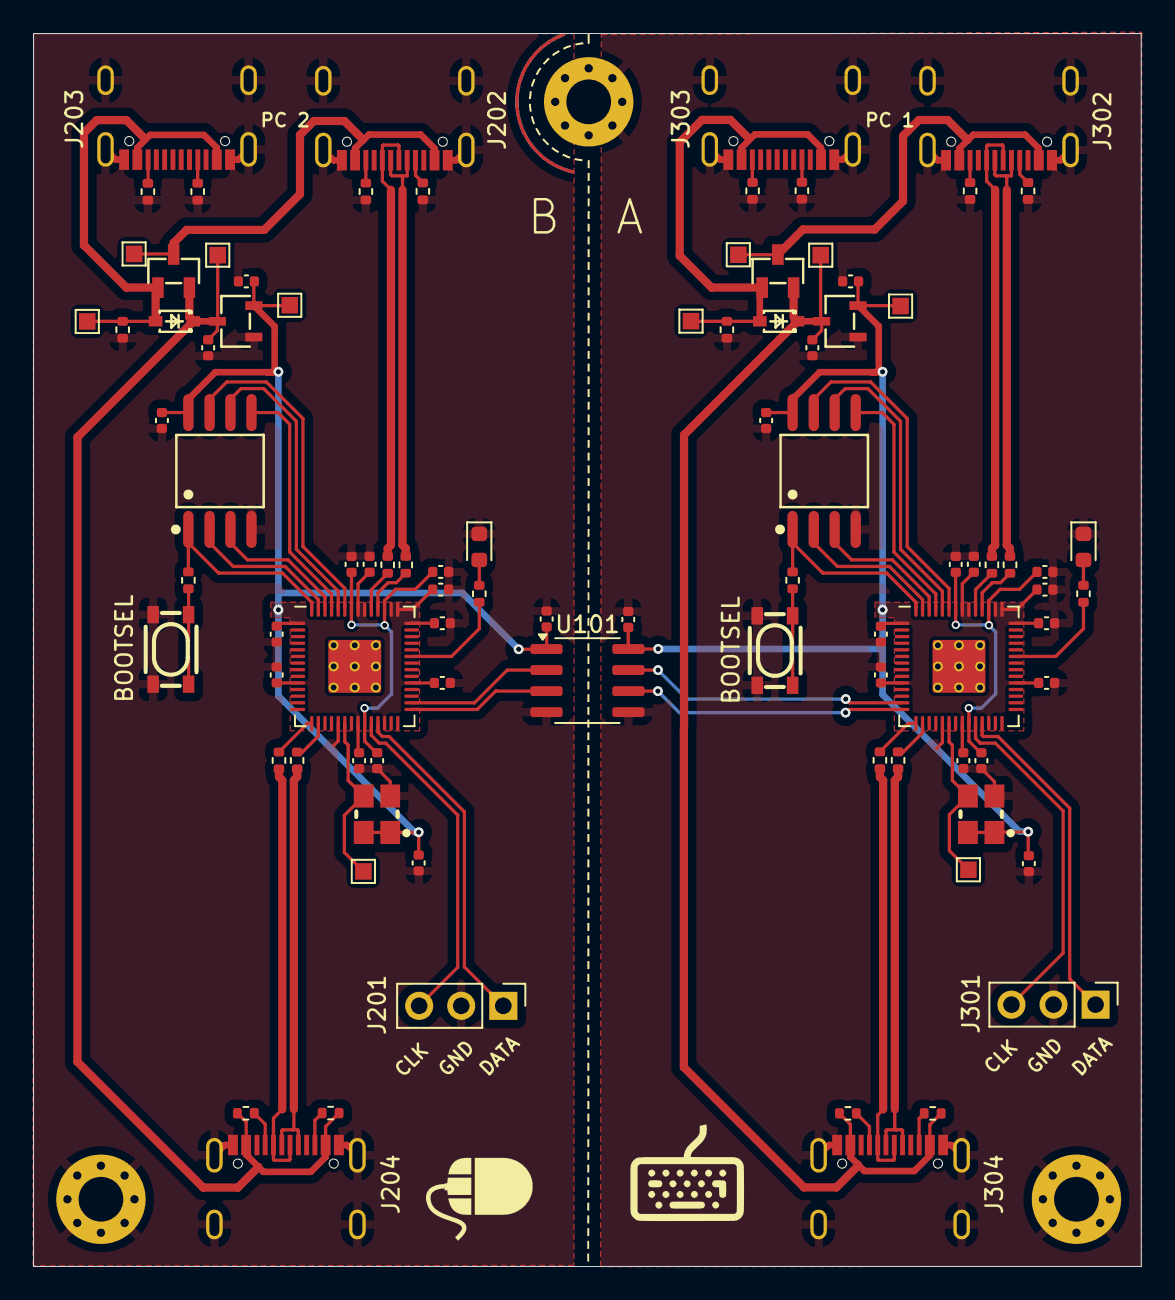
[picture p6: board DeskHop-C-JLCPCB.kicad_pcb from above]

Board: 2 copper layers, 66.9 x 74.5 mm, 94 parts (0 on the bottom side), 68 nets.

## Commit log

2024-02-26 Initial commit of JLCPCB-specific version.
    [DeskHop-B_Cu.gbr, DeskHop-B_Mask.gbr, DeskHop-B_Paste.gbr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]
2024-03-13 Initial commit of Type-C board, without Pico modules.
    [DeskHop-C-JLCPCB.kicad_pcb, DeskHop-C-JLCPCB.kicad_sch, DeskHop_JLCPCB.kicad_pcb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]
2024-03-13 Add test points for power supplies and oscillator.
    [DeskHop-C-JLCPCB.kicad_pcb, core.kicad_sch]
2024-03-15 Ignore log files from KiCAD plugins.
2024-03-16 Update schematic with MPN/LCSC, and update manual BOM.
    [DeskHop-C-JLCPCB.kicad_pcb, DeskHop-C-JLCPCB.kicad_sch, LCSC_BOM.xls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]
2024-03-17 First round of production cleanup.
    [DeskHop-C-JLCPCB.kicad_pcb, DeskHop-C-JLCPCB.kicad_sch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]
2024-03-17 Add decoupling caps for oscillators.
    [DeskHop-C-JLCPCB.kicad_pcb, bom.csv, core.kicad_sch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]
2024-03-17 More improvements:
    * Used different GPIOs for the device USB so the traces can be kept
    away from the 12MHz oscillator circuit.
    * Increased size of VBUS traces so that 1.5A@5V can be safely carried
    from the input connectors to the output connectors.
    * Various minor tweaks.
    [DeskHop-C-JLCPCB.kicad_pcb, bom.csv, core.kicad_sch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]
2024-03-18 Make changes needed to get 3-D model working properly.
    [DeskHop-C-JLCPCB.kicad_pcb]
2024-03-18 Relocate various items to improve silkscreen placement.
    [DeskHop-C-JLCPCB.kicad_pcb]
2024-03-18 Adjust mounting hole positions to match original board.
    [DeskHop-C-JLCPCB.kicad_pcb]
2024-03-19 Use better net labels for UART links.
    [DeskHop-C-JLCPCB.kicad_pcb, DeskHop-C-JLCPCB.kicad_sch, core.kicad_sch]
2024-03-23 Lots of improvements:
    * Modified footprint for USB Type-C connector to use an NPTH for the
    plastic locator pins.
    * Connected USB SHIELD to GND as required by the USB spec.
    * Simplified trace routing and eliminated most vias.
    * Improved VUSB trace routing and sizing.
    [DeskHop-C-JLCPCB.kicad_pcb, DeskHop-C-JLCPCB.kicad_sch, core.kicad_sch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]
2024-03-23 Switch to a smaller pushbutton (similar to the one on the Pico)
    Edit imported symbols to use 'LCSC' instead of 'LCSC Part' field name
    [DeskHop-C-JLCPCB.kicad_pcb, bom.csv, core.kicad_sch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]

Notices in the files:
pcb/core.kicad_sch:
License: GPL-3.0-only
